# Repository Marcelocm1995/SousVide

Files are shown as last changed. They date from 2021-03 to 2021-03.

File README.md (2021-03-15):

# SousVide
This project is a thermo-circulator for cooking meats, fishes, etc. It's consists, basically, in a resistance thats heat up water at pre-determinatade temperature and time(or not).

# Bill Of Materials
* 500 Watts resistance
* DS18B20 Temperature sensor
* Water pump (from aquarium)
* 5V power supply (from smartphone charger)
* BluePill (STM32F103C8T6) 
* Rotary Encoder
* OLED DISPLAY
* 5V Relay
* 1N4148 Diode
* 5V Beep
* 2x BC548 transistors
* 3x 4k7 resistors
* 5mm LED
* 1k resistor

# How It Works:
This project have two operations modes:
* Heat(Aquecimento), will only heat water and keep at user determinatade temperature for indeterminatade time.
* Cooking (Cozinhar), will heat and keep water temperature for user determinatade temperature and time.

# Software:
It uses cubeMX for generate a pre-code. Compiler Keil uVision, but you can easily migrate to another suported compiler by cubeMX, like IAR.
The software first shows on display the operations modes for user and wait for a choice. Case Heat (aquecimento) mode is chose, display will ask for witch temperature user want to set, and will start the heating process. In this mode, when temperature achieve the setpoint some beeps will be emitted.
Case Cooking (Cozinhar) mode is chose, display will ask for witch temperature user want to set, and then witch time user want to set. In this mode, when timer done some beeps will be emitted.
To cancel any of these process is necessary to hold on encoder button for some seconds.

**You need to extract the "Drivers.zip" to compile this software**

## Control
It uses a simple bang-bang control (on/off) with a offset of +/- 0.2°C, but if you want it have a PID mode (at line 48 of main.c, uncalibrated).

## Debug
It have a USB CDC for debug, to enable this uncomment line 58 of main.c

# Hardware:
This hardware uses the schematic bellow:

<a href="https://imgur.com/b3Bf7M9">source: imgur.com</a>

* The signal pin is a PWM working with 0% or 100% in bang-bang mode, in PID mode you will need a solid-state relay.
* Use a power supply at least 250mA.
* Pay attention with current capacite of conductors in heater part 
* Use a shielded waterproof DS18B20

# Enclosure
I made a 3D printed enclosure for this project, STL's and STEP's are avaiable for download on this repository.
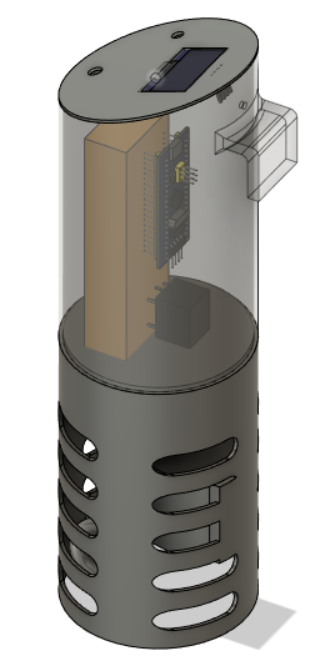
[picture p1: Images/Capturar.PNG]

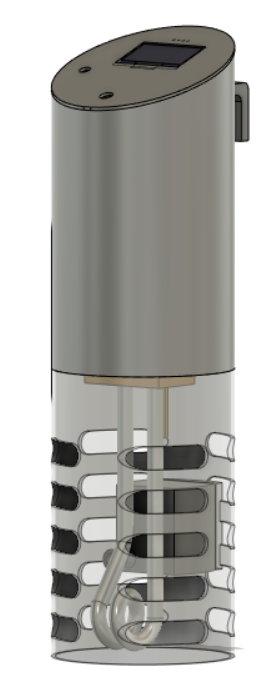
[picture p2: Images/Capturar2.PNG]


# Assembly
The middle part of enclosure needs to seal with silicone, like bellow:
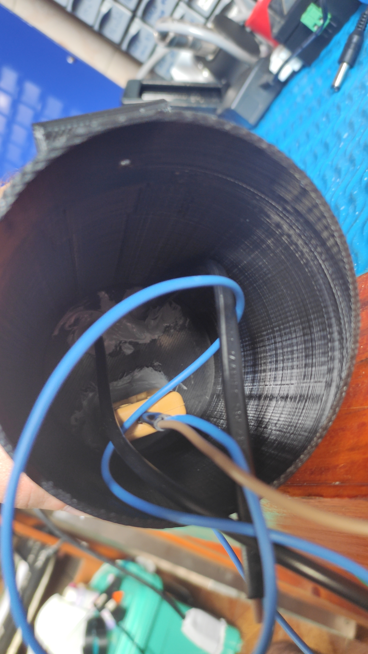
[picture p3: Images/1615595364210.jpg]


# Final project
alt text for screen readers Text to show on mouseover
IMAGE ALT TEXT HERE (https://www.youtube.com/watch?v=m6A6xz97m30)

https://www.youtube.com/watch?v=m6A6xz97m30

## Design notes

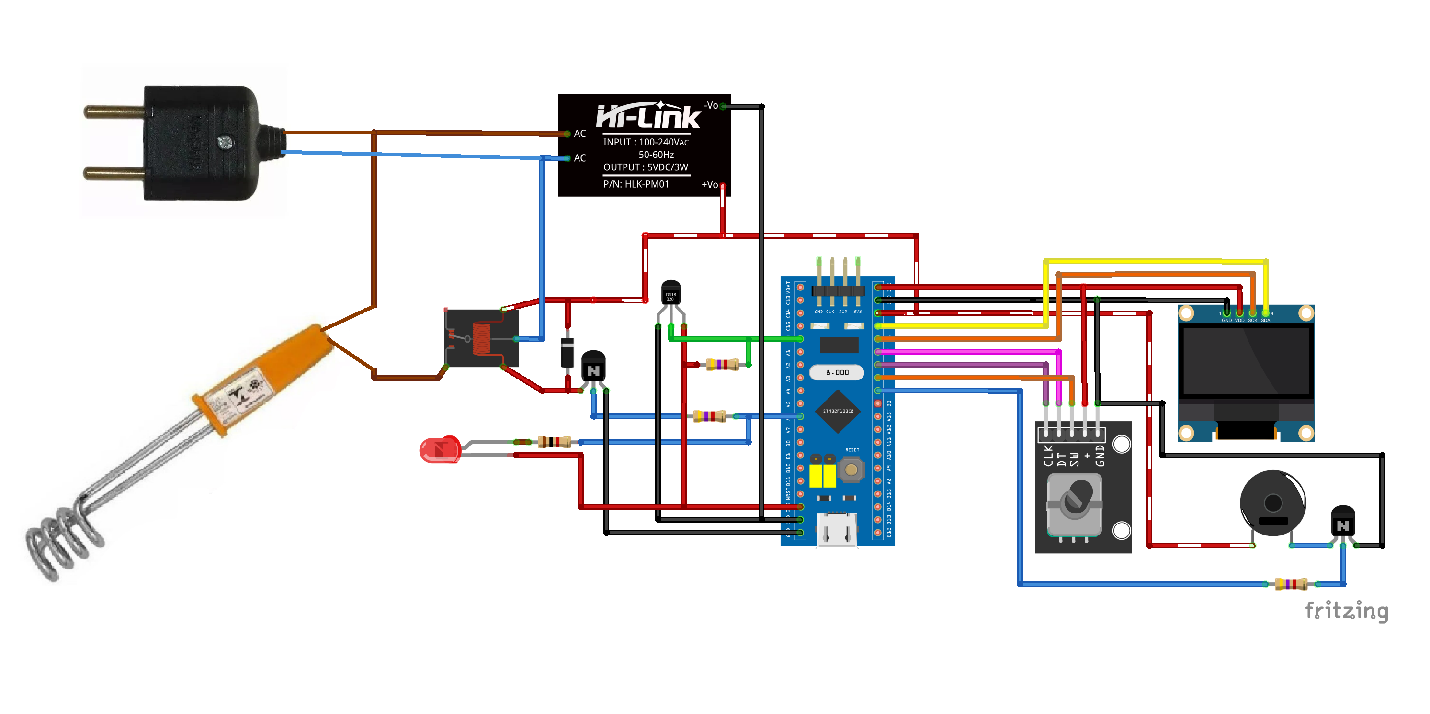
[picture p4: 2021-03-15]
Images/Untitled Sketch_bb.png

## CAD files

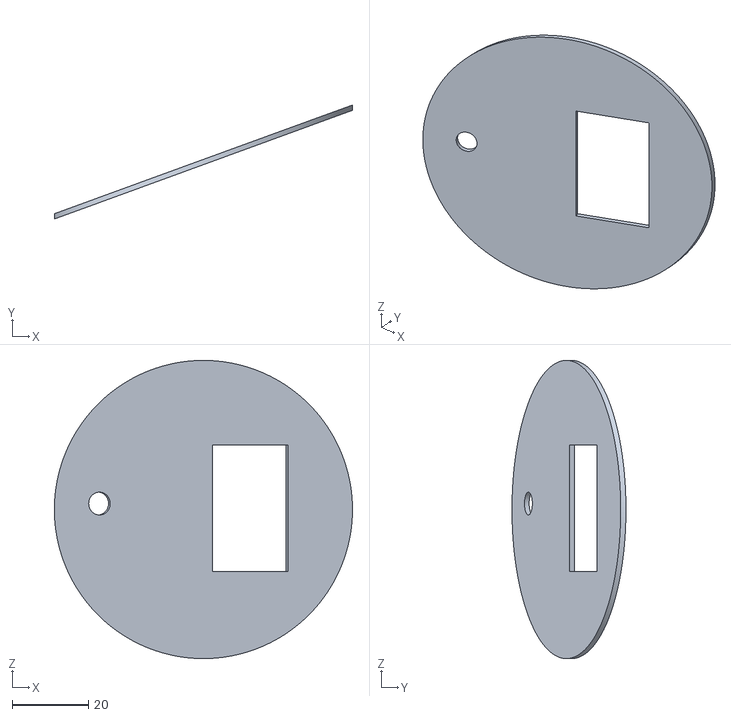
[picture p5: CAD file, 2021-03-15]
STL/tampa_superior.stl
78.2 x 29.9 x 78.2

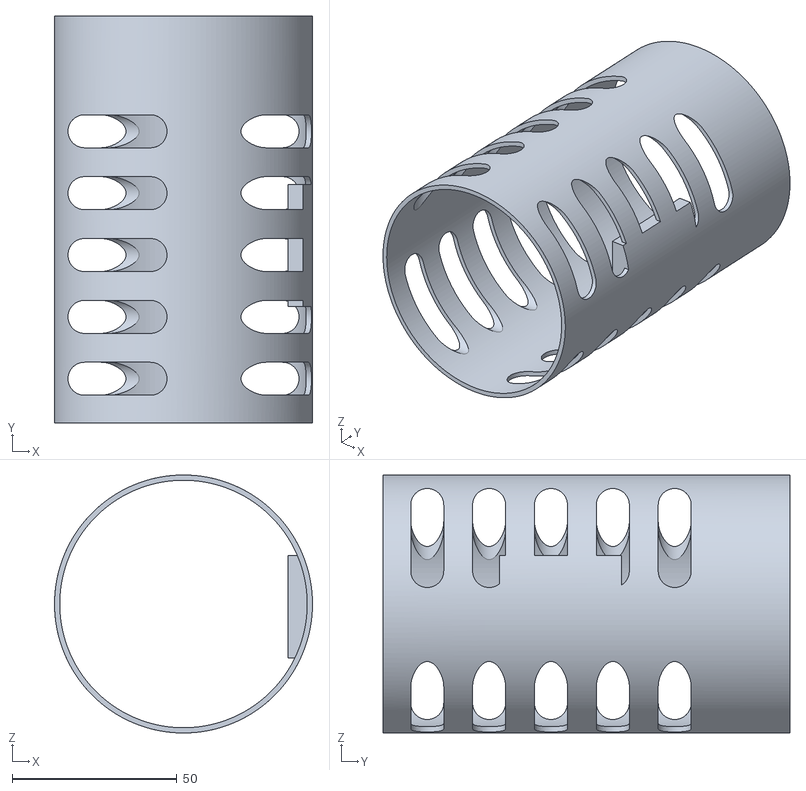
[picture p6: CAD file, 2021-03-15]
STL/corpo_inferior.stl
78.2 x 123.4 x 78.2

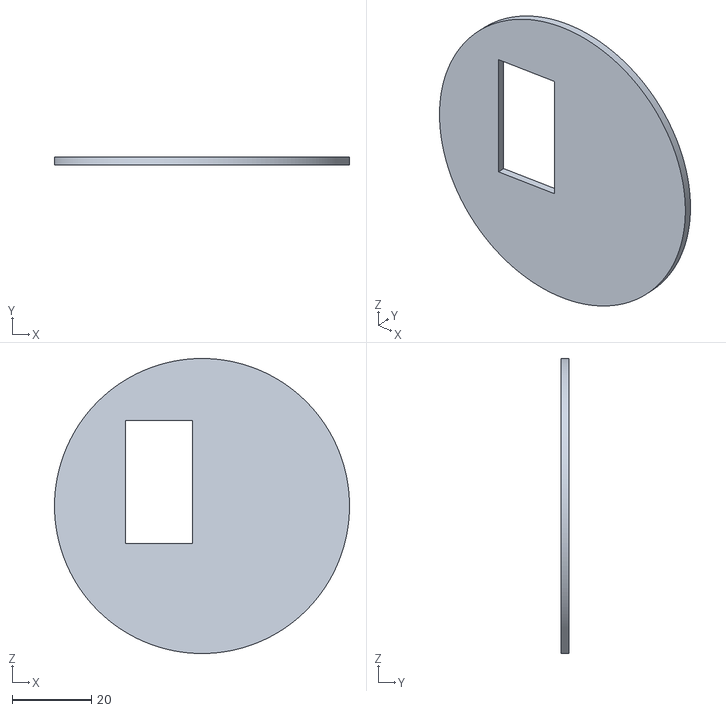
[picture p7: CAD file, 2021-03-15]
STL/tampa_inferior.stl
74.6 x 2.00 x 74.6

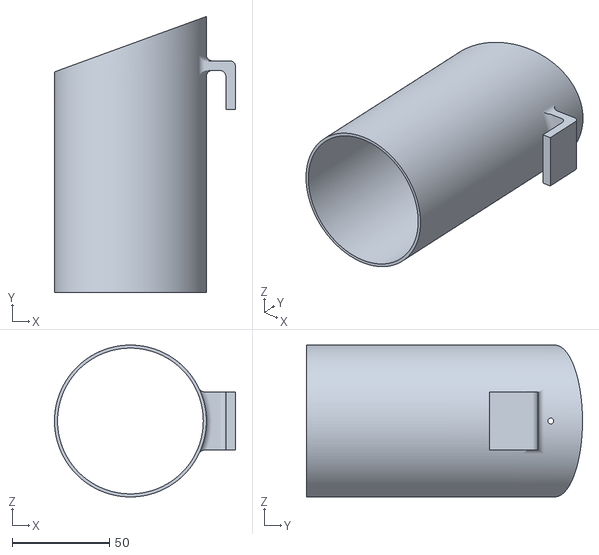
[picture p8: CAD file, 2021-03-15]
STL/corpo_superior.stl
93.2 x 142.1 x 78.2

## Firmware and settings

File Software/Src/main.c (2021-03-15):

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
/* Includes ------------------------------------------------------------------*/
#include "main.h"
#include "usb_device.h"

/* USER CODE BEGIN Includes */

#include "fonts.h"
#include "ssd1306.h"
#include "test.h"
#include "string.h"
#include "stdio.h"
#include "stdlib.h"
#include "usbd_cdc_if.h"

/* USER CODE END Includes */

/* USER CODE BEGIN PD */

//#define USE_PID
//#define USE_FILTER

#ifdef USE_PID
#define Kp 1.0
#define Ki 1.0
#define Kd 1.0
#define SAMPLE_TIME 1
#endif

#define DS18B20_PORT GPIOA
#define DS18B20_PIN GPIO_PIN_1

//#define DEBUG

/* USER CODE END PD */

/* USER CODE BEGIN PM */

#define LED_ON HAL_GPIO_WritePin(LED1_GPIO_Port, LED1_Pin, GPIO_PIN_RESET)
#define LED_OFF HAL_GPIO_WritePin(LED1_GPIO_Port, LED1_Pin, GPIO_PIN_SET)

#define BEEP_ON HAL_GPIO_WritePin(BUZZER_GPIO_Port, BUZZER_Pin, GPIO_PIN_SET)
#define BEEP_OFF HAL_GPIO_WritePin(BUZZER_GPIO_Port, BUZZER_Pin, GPIO_PIN_RESET)

/* USER CODE END PM */

ADC_HandleTypeDef hadc1;

I2C_HandleTypeDef hi2c1;

TIM_HandleTypeDef htim1;
TIM_HandleTypeDef htim2;
TIM_HandleTypeDef htim3;
TIM_HandleTypeDef htim4;

/* USER CODE BEGIN PV */
int TEMPOOO;
int SECOND_TIMER;

int SECOND, MINUTE, HOUR;
int SET_SECOND, SET_MINUTE, SET_HOUR;
int TOTAL_SET_SECOND;
int TOTAL_SET_SECOND_COUNTDOWN;

unsigned int SETPOINT_TEMPERAURE;

float TEMPERATURE, 
			LAST_TEMPERATURE,
			TEMPERATURE_RAW,
			FILTER_FACTOR = 5,
			Ts = 1.0f,
			TEMPERATURE_OFFSET = 0.2f;

float ERROR_MEASURED;
float PROPORTIONAL;
float INTEGRATOR;
float DERIVATIVE;
float PID;

int BLYNK_OLED;

int encoderCount, encoderDirection;
int SW_ALREADY_PRESSED;


char strbuffer[64];

int liga = 0;


/* USER CODE END PV */

void SystemClock_Config(void);
static void MX_GPIO_Init(void);
static void MX_ADC1_Init(void);
static void MX_TIM4_Init(void);
static void MX_I2C1_Init(void);
static void MX_TIM3_Init(void);
static void MX_TIM1_Init(void);
static void MX_TIM2_Init(void);
/* USER CODE BEGIN PFP */

float Temp_Read(void);
void heat_function(void);
void cook_function(void);
void delay_us (uint16_t us);
void Set_Pin_Output (GPIO_TypeDef *GPIOx, uint16_t GPIO_Pin);
void Set_Pin_Input (GPIO_TypeDef *GPIOx, uint16_t GPIO_Pin);
uint8_t DS18B20_Start (void);
void DS18B20_Write (uint8_t data);
uint8_t DS18B20_Read (void);
void beep(int delay);

extern uint8_t CDC_Transmit_FS(uint8_t* Buf, uint16_t Len);

/* USER CODE END PFP */

/**
  * @brief  The application entry point.
  * @retval int
  */
int main(void)
{
  /* MCU Configuration--------------------------------------------------------*/

  /* Reset of all peripherals, Initializes the Flash interface and the Systick. */
  HAL_Init();

  /* Configure the system clock */
  SystemClock_Config();

  /* Initialize all configured peripherals */
  MX_GPIO_Init();
  MX_ADC1_Init();
  MX_TIM4_Init();
  MX_USB_DEVICE_Init();
  MX_I2C1_Init();
  MX_TIM3_Init();
  MX_TIM1_Init();
  MX_TIM2_Init();
  /* USER CODE BEGIN 2 */

	HAL_Delay(1000);
		
	char strBuffer[] = "Ola\n\r";
	CDC_Transmit_FS((uint8_t*)strBuffer, strlen(strBuffer));
	
	SSD1306_Init();  // initialise
	SSD1306_Clear();
	
	beep(200);
	   
	SSD1306_GotoXY (2,0);
  SSD1306_Puts("Sous", &Font_16x26, 1);
  SSD1306_GotoXY (60, 30);
  SSD1306_Puts("Vide", &Font_16x26, 1);
  SSD1306_UpdateScreen(); //display

	HAL_TIM_Encoder_Start(&htim4, TIM_CHANNEL_ALL);
	__HAL_TIM_SET_AUTORELOAD(&htim4, 4*2);
	
	HAL_TIM_PWM_Start(&htim3, TIM_CHANNEL_1);
	__HAL_TIM_SET_COMPARE(&htim3, TIM_CHANNEL_1, 0);
	
	LED_ON;
	HAL_Delay(2000);
	SSD1306_Clear();
	
	HAL_TIM_Base_Start(&htim2);
	
	LED_OFF;
			
  /* USER CODE END 2 */

  /* Infinite loop */
  /* USER CODE BEGIN WHILE */
  while (1)
  {
		encoderCount = __HAL_TIM_GET_COUNTER(&htim4) / 4;
		SSD1306_GotoXY (22,0);
		SSD1306_Puts("Aquecer", &Font_11x18, 1);
		SSD1306_GotoXY (22,30);
		SSD1306_Puts("Cozinhar", &Font_11x18, 1);
		
		char strBuffer[] = "Ola\n\r";
		CDC_Transmit_FS((uint8_t*)strBuffer, strlen(strBuffer));
		
		if(encoderCount == 1)
		{
			SSD1306_GotoXY (0,0);
			SSD1306_Puts("->", &Font_11x18, 1);
			SSD1306_GotoXY (0,30);
			SSD1306_Puts("  ", &Font_11x18, 1);
		}
		
		if(encoderCount == 0)
		{
			SSD1306_GotoXY (0,30);
			SSD1306_Puts("->", &Font_11x18, 1);
			SSD1306_GotoXY (0,0);
			SSD1306_Puts("  ", &Font_11x18, 1);
		}
		SSD1306_UpdateScreen();
		
		if((HAL_GPIO_ReadPin(SW_ENC_GPIO_Port, SW_ENC_Pin) == 1) && (SW_ALREADY_PRESSED == 1))
				SW_ALREADY_PRESSED = 0;
		
		if((HAL_GPIO_ReadPin(SW_ENC_GPIO_Port, SW_ENC_Pin) == 0) && (SW_ALREADY_PRESSED == 0))
			{
				HAL_Delay(100);
				if((HAL_GPIO_ReadPin(SW_ENC_GPIO_Port, SW_ENC_Pin) == 0) && (SW_ALREADY_PRESSED == 0))
				{
					SW_ALREADY_PRESSED = 1;
					beep(200);
					if(encoderCount == 1)
					{
						SSD1306_Clear();
						heat_function();
						__HAL_TIM_SET_COUNTER(&htim4, 0);
					}
					else
					{
						SSD1306_Clear();
						cook_function();
						__HAL_TIM_SET_COUNTER(&htim4, 0);
					}
				}
			}
		
    /* USER CODE END WHILE */

    /* USER CODE BEGIN 3 */
  }
  /* USER CODE END 3 */
}

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
/* USER CODE BEGIN 4 */

void heat_function(void)
{
	int STAGE = 0;
	
	sprintf(strbuffer, "Selecione a");
	SSD1306_GotoXY(2, 0);
	SSD1306_Puts(strbuffer, &Font_11x18, 1);
	
	sprintf(strbuffer, "Temperatura");
	SSD1306_GotoXY(2, 20);
	SSD1306_Puts(strbuffer, &Font_11x18, 1);
	
	__HAL_TIM_SET_COUNTER(&htim4, 0);
	__HAL_TIM_SET_AUTORELOAD(&htim4, (4 * 100)-1);
  while(STAGE == 0)
	{
		encoderCount = __HAL_TIM_GET_COUNTER(&htim4)/4;	
		sprintf(strbuffer, "%02i C",encoderCount);
		SSD1306_GotoXY(40, 42);
		SSD1306_Puts(strbuffer, &Font_11x18, 0);
		SSD1306_UpdateScreen();
		
		if((HAL_GPIO_ReadPin(SW_ENC_GPIO_Port, SW_ENC_Pin) == 1) && (SW_ALREADY_PRESSED == 1))
			SW_ALREADY_PRESSED = 0;
		
		if((HAL_GPIO_ReadPin(SW_ENC_GPIO_Port, SW_ENC_Pin) == 0) && (SW_ALREADY_PRESSED == 0))
		{
			HAL_Delay(100);
			if((HAL_GPIO_ReadPin(SW_ENC_GPIO_Port, SW_ENC_Pin) == 0) && (SW_ALREADY_PRESSED == 0))
			{
				SW_ALREADY_PRESSED = 1;
				beep(200);
				STAGE++;
				SETPOINT_TEMPERAURE = encoderCount;
				SSD1306_Clear();
			}
		}
	}
	
	while(STAGE == 1)
	{
		int t_in = HAL_GetTick();
		
		#ifdef USE_FILTER
		TEMPERATURE_RAW = Temp_Read();
		TEMPERATURE =  ((FILTER_FACTOR * Ts * TEMPERATURE_RAW) + (LAST_TEMPERATURE)) /( 1 + (FILTER_FACTOR * Ts));
    LAST_TEMPERATURE = TEMPERATURE;
		
		#else
		TEMPERATURE = Temp_Read();
		
		#endif
		
		#ifdef USE_PID
    ERROR_MEASURED = SETPOINT_TEMPERAURE - TEMPERATURE;
    
    PROPORTIONAL = Kp * ERROR_MEASURED;
    INTEGRATOR += (Ki * ERROR_MEASURED) * SAMPLE_TIME;
    DERIVATIVE = ((TEMPERATURE - LAST_TEMPERATURE) * Kd) / SAMPLE_TIME;
   
		if(INTEGRATOR > 1000)
			INTEGRATOR = 1000;
	 
		if(INTEGRATOR < 0)
			INTEGRATOR = 0;
    

    PID = PROPORTIONAL + INTEGRATOR - DERIVATIVE;
    
		__HAL_TIM_SET_COMPARE(&htim3, TIM_CHANNEL_1, PID);
    
		LAST_TEMPERATURE = TEMPERATURE;
		
		#else
		if(TEMPERATURE > SETPOINT_TEMPERAURE + TEMPERATURE_OFFSET)
		{
			liga = 0;
			beep(200);
			LED_OFF;
			__HAL_TIM_SET_COMPARE(&htim3, TIM_CHANNEL_1, 0);
		}
		
		if(TEMPERATURE < SETPOINT_TEMPERAURE - TEMPERATURE_OFFSET)
		{
			liga = 1;
			LED_ON;
			__HAL_TIM_SET_COMPARE(&htim3, TIM_CHANNEL_1, 100);
		}
		#endif
		
		HAL_Delay(156);//necessario para dar 1hz no ciclo
		
		BLYNK_OLED = !BLYNK_OLED;
		SSD1306_GotoXY(12, 0);
		SSD1306_Puts("Aquecendo", &Font_11x18, BLYNK_OLED);
		
		SSD1306_GotoXY(10, 35);
		SSD1306_Puts("Atual", &Font_7x10, 1);
		sprintf(strbuffer, "%.1fC ", TEMPERATURE);
		SSD1306_GotoXY(2, 45);
		SSD1306_Puts(strbuffer, &Font_11x18, 1);
		
		SSD1306_GotoXY(80, 35);
		SSD1306_Puts("Alvo", &Font_7x10, 1);
		sprintf(strbuffer, "%02iC", SETPOINT_TEMPERAURE);
		SSD1306_GotoXY(80, 45);
		SSD1306_Puts(strbuffer, &Font_11x18, 1);
		
		SSD1306_UpdateScreen();
		
		#ifdef DEBUG
		sprintf(strbuffer, "Temperatura atual %.1fC\n\r", TEMPERATURE);
		CDC_Transmit_FS((uint8_t*)strbuffer, strlen(strbuffer));
		sprintf(strbuffer, "Temperatura Alvo %iC\n\r", SETPOINT_TEMPERAURE);
		CDC_Transmit_FS((uint8_t*)strbuffer, strlen(strbuffer));
		#endif
		
		if((HAL_GPIO_ReadPin(SW_ENC_GPIO_Port, SW_ENC_Pin) == 1) && (SW_ALREADY_PRESSED == 1))
			SW_ALREADY_PRESSED = 0;
		
		if((HAL_GPIO_ReadPin(SW_ENC_GPIO_Port, SW_ENC_Pin) == 0) && (SW_ALREADY_PRESSED == 0))
		{
			HAL_Delay(1000);
			if((HAL_GPIO_ReadPin(SW_ENC_GPIO_Port, SW_ENC_Pin) == 0) && (SW_ALREADY_PRESSED == 0))
			{
				SW_ALREADY_PRESSED = 1;
				beep(200);
				__HAL_TIM_SET_COMPARE(&htim3, TIM_CHANNEL_1, 0);
				liga = 0;
				LED_OFF;
				SSD1306_Clear();
				return;
			}
		}
		int t_end = HAL_GetTick();
		TEMPOOO = t_end - t_in;
	}
}

void cook_function()
{
	int STAGE = 0;
	
	sprintf(strbuffer, "Selecione a");
	SSD1306_GotoXY(2, 0);
	SSD1306_Puts(strbuffer, &Font_11x18, 1);
	
	sprintf(strbuffer, "Temperatura");
	SSD1306_GotoXY(2, 20);
	SSD1306_Puts(strbuffer, &Font_11x18, 1);
	
	__HAL_TIM_SET_COUNTER(&htim4, 0);
	__HAL_TIM_SET_AUTORELOAD(&htim4, (4 * 100)-1);
  while(STAGE == 0)
	{
		encoderCount = __HAL_TIM_GET_COUNTER(&htim4)/4;
		sprintf(strbuffer, "%02i C",encoderCount);
		SSD1306_GotoXY(40, 42);
		SSD1306_Puts(strbuffer, &Font_11x18, 0);
		SSD1306_UpdateScreen();
		
		if((HAL_GPIO_ReadPin(SW_ENC_GPIO_Port, SW_ENC_Pin) == 1) && (SW_ALREADY_PRESSED == 1))
			SW_ALREADY_PRESSED = 0;
		
		if((HAL_GPIO_ReadPin(SW_ENC_GPIO_Port, SW_ENC_Pin) == 0) && (SW_ALREADY_PRESSED == 0))
		{
			HAL_Delay(100);
			if((HAL_GPIO_ReadPin(SW_ENC_GPIO_Port, SW_ENC_Pin) == 0) && (SW_ALREADY_PRESSED == 0))
			{
				SW_ALREADY_PRESSED = 1;
				beep(200);
				STAGE++;
				SETPOINT_TEMPERAURE = encoderCount;
			}
		}
	}
	SSD1306_Clear();
	sprintf(strbuffer, "Selecione o");
	SSD1306_GotoXY(2, 0);
	SSD1306_Puts(strbuffer, &Font_11x18, 1);
	
	sprintf(strbuffer, "Tempo       ");
	SSD1306_GotoXY(2, 20);
	SSD1306_Puts(strbuffer, &Font_11x18, 1);
	
	__HAL_TIM_SET_COUNTER(&htim4, 0);
	__HAL_TIM_SET_AUTORELOAD(&htim4, (4 * 100)-1);
  while(STAGE == 1)
	{
		encoderCount = __HAL_TIM_GET_COUNTER(&htim4)/4;
		sprintf(strbuffer, "%02ih",encoderCount);
		SSD1306_GotoXY(2, 40);
		SSD1306_Puts(strbuffer, &Font_11x18, 0);
		
		sprintf(strbuffer, ":00m:00s");
		SSD1306_Puts(strbuffer, &Font_11x18, 1);
		
		SSD1306_UpdateScreen();
		
		if((HAL_GPIO_ReadPin(SW_ENC_GPIO_Port, SW_ENC_Pin) == 1) && (SW_ALREADY_PRESSED == 1))
			SW_ALREADY_PRESSED = 0;
		
		if((HAL_GPIO_ReadPin(SW_ENC_GPIO_Port, SW_ENC_Pin) == 0) && (SW_ALREADY_PRESSED == 0))
		{
			HAL_Delay(100);
			if((HAL_GPIO_ReadPin(SW_ENC_GPIO_Port, SW_ENC_Pin) == 0) && (SW_ALREADY_PRESSED == 0))
			{
				SW_ALREADY_PRESSED = 1;
				beep(200);
				STAGE++;
				SET_HOUR = encoderCount;
			}
		}
	}
	
	__HAL_TIM_SET_COUNTER(&htim4, 0);
	__HAL_TIM_SET_AUTORELOAD(&htim4, 4 * 60);
  while(STAGE == 2)
	{
		encoderCount = __HAL_TIM_GET_COUNTER(&htim4)/4;
		sprintf(strbuffer, "%02ih:", SET_HOUR);
		SSD1306_GotoXY(2, 40);
		SSD1306_Puts(strbuffer, &Font_11x18, 1);
		
		sprintf(strbuffer, "%02im", encoderCount);
		SSD1306_Puts(strbuffer, &Font_11x18, 0);
		
		sprintf(strbuffer, ":00s");
		SSD1306_Puts(strbuffer, &Font_11x18, 1);
		
		SSD1306_UpdateScreen();
		
		if((HAL_GPIO_ReadPin(SW_ENC_GPIO_Port, SW_ENC_Pin) == 1) && (SW_ALREADY_PRESSED == 1))
			SW_ALREADY_PRESSED = 0;
		
		if((HAL_GPIO_ReadPin(SW_ENC_GPIO_Port, SW_ENC_Pin) == 0) && (SW_ALREADY_PRESSED == 0))
		{
			HAL_Delay(100);
			if((HAL_GPIO_ReadPin(SW_ENC_GPIO_Port, SW_ENC_Pin) == 0) && (SW_ALREADY_PRESSED == 0))
			{
				SW_ALREADY_PRESSED = 1;
				beep(200);
				STAGE++;
				SET_MINUTE = encoderCount;
			}
		}
	}
	
	__HAL_TIM_SET_COUNTER(&htim4, 0);
	__HAL_TIM_SET_AUTORELOAD(&htim4, 4 * 60);
  while(STAGE == 3)
	{
		encoderCount = __HAL_TIM_GET_COUNTER(&htim4)/4;
		sprintf(strbuffer, "%02ih:", SET_HOUR);
		SSD1306_GotoXY(2, 40);
		SSD1306_Puts(strbuffer, &Font_11x18, 1);
		
		sprintf(strbuffer, "%02im:", SET_MINUTE);
		SSD1306_Puts(strbuffer, &Font_11x18, 1);
		
		sprintf(strbuffer, "%02is",encoderCount);
		SSD1306_Puts(strbuffer, &Font_11x18, 0);
		SSD1306_UpdateScreen();
		
		if((HAL_GPIO_ReadPin(SW_ENC_GPIO_Port, SW_ENC_Pin) == 1) && (SW_ALREADY_PRESSED == 1))
			SW_ALREADY_PRESSED = 0;
		
		if((HAL_GPIO_ReadPin(SW_ENC_GPIO_Port, SW_ENC_Pin) == 0) && (SW_ALREADY_PRESSED == 0))
		{
			HAL_Delay(100);
			if((HAL_GPIO_ReadPin(SW_ENC_GPIO_Port, SW_ENC_Pin) == 0) && (SW_ALREADY_PRESSED == 0))
			{
				SW_ALREADY_PRESSED = 1;
				beep(200);
				STAGE++;
				SET_SECOND = encoderCount;
			}
		}
	}
	
	SSD1306_Clear();
	HOUR = SET_HOUR; MINUTE = SET_MINUTE; SECOND = SET_SECOND;
	TOTAL_SET_SECOND = (SET_HOUR * 3600) + (SET_MINUTE * 60) + SET_SECOND;
	TOTAL_SET_SECOND_COUNTDOWN = TOTAL_SET_SECOND;
	SECOND_TIMER = 0;
	HAL_TIM_Base_Start_IT(&htim1);
	
	while((STAGE == 4) && (TOTAL_SET_SECOND > SECOND_TIMER))
	{
		int t_in = HAL_GetTick();
	
		#ifdef USE_FILTER
		TEMPERATURE_RAW = Temp_Read();
		TEMPERATURE =  ((FILTER_FACTOR * Ts * TEMPERATURE_RAW) + (LAST_TEMPERATURE)) /( 1 + (FILTER_FACTOR * Ts));
    LAST_TEMPERATURE = TEMPERATURE;
		
		#else
		TEMPERATURE = Temp_Read();
		
		#endif
		
		#ifdef USE_PID
    ERROR_MEASURED = SETPOINT_TEMPERAURE - TEMPERATURE;
    
    PROPORTIONAL = Kp * ERROR_MEASURED;
    INTEGRATOR += (Ki * ERROR_MEASURED) * SAMPLE_TIME;
    DERIVATIVE = ((TEMPERATURE - LAST_TEMPERATURE) * Kd) / SAMPLE_TIME;
   
		if(INTEGRATOR > 1000)
			INTEGRATOR = 1000;
	 
		if(INTEGRATOR < 0)
			INTEGRATOR = 0;
    

    PID = PROPORTIONAL + INTEGRATOR - DERIVATIVE;
    
		__HAL_TIM_SET_COMPARE(&htim3, TIM_CHANNEL_1, PID);
    
		LAST_TEMPERATURE = TEMPERATURE;
		#else
		if(TEMPERATURE > SETPOINT_TEMPERAURE + TEMPERATURE_OFFSET)
		{
			liga = 0;
			LED_OFF;
			__HAL_TIM_SET_COMPARE(&htim3, TIM_CHANNEL_1, 0);
		}
		
		if(TEMPERATURE < SETPOINT_TEMPERAURE - TEMPERATURE_OFFSET)
		{
			liga = 1;
			LED_ON;
			__HAL_TIM_SET_COMPARE(&htim3, TIM_CHANNEL_1, 100);
		}
		#endif
		
		HAL_Delay(153);//necessario para dar 1hz no ciclo
		
		HOUR = TOTAL_SET_SECOND_COUNTDOWN / 3600;
		MINUTE = (TOTAL_SET_SECOND_COUNTDOWN % 3600) / 60;
		SECOND = (TOTAL_SET_SECOND_COUNTDOWN % 3600) % 60;
		
		BLYNK_OLED = !BLYNK_OLED;
		SSD1306_GotoXY(10, 0);
		SSD1306_Puts("Tempo faltante", &Font_7x10, BLYNK_OLED);
		sprintf(strbuffer, "%02ih:%02im:%02is", HOUR, MINUTE, SECOND);
		SSD1306_GotoXY(4, 11);
		SSD1306_Puts(strbuffer, &Font_11x18, 1);
		
		SSD1306_GotoXY(10, 35);
		SSD1306_Puts("Atual", &Font_7x10, 1);
		sprintf(strbuffer, "%.1fC ", TEMPERATURE);
		SSD1306_GotoXY(2, 45);
		SSD1306_Puts(strbuffer, &Font_11x18, 1);
		
		SSD1306_GotoXY(80, 35);
		SSD1306_Puts("Alvo", &Font_7x10, 1);
		sprintf(strbuffer, "%02iC", SETPOINT_TEMPERAURE);
		SSD1306_GotoXY(80, 45);
		SSD1306_Puts(strbuffer, &Font_11x18, 1);
		
		SSD1306_UpdateScreen();
		
		#ifdef DEBUG
		sprintf(strbuffer, "\nTempo faltante %02ih:%02im:%02is\n", HOUR, MINUTE, SECOND);
		CDC_Transmit_FS((uint8_t*)strbuffer, strlen(strbuffer));
		sprintf(strbuffer, "Temperatura atual %.1fC\n", TEMPERATURE);
		CDC_Transmit_FS((uint8_t*)strbuffer, strlen(strbuffer));
		sprintf(strbuffer, "Temperatura alvo %iC\n", SETPOINT_TEMPERAURE);
		CDC_Transmit_FS((uint8_t*)strbuffer, strlen(strbuffer));
		#endif
		
		if((HAL_GPIO_ReadPin(SW_ENC_GPIO_Port, SW_ENC_Pin) == 1) && (SW_ALREADY_PRESSED == 1))
			SW_ALREADY_PRESSED = 0;
		
		if((HAL_GPIO_ReadPin(SW_ENC_GPIO_Port, SW_ENC_Pin) == 0) && (SW_ALREADY_PRESSED == 0))
		{
			HAL_Delay(3000);
			if((HAL_GPIO_ReadPin(SW_ENC_GPIO_Port, SW_ENC_Pin) == 0) && (SW_ALREADY_PRESSED == 0))
			{
				SW_ALREADY_PRESSED = 1;
				beep(200);
				__HAL_TIM_SET_COMPARE(&htim3, TIM_CHANNEL_1, 0);
				SSD1306_Clear();
				HAL_TIM_Base_Stop_IT(&htim1);
				__HAL_TIM_SET_COUNTER(&htim1, 0);
				liga = 0;
				LED_OFF;
				for(int k = 0; k < 3; k++)
				{
					BEEP_ON;
					LED_ON;
					HAL_Delay(200);
					BEEP_OFF;
					LED_OFF;
					HAL_Delay(100);
				}
				return;
			}
		}
		int t_end = HAL_GetTick();
		TEMPOOO = t_end - t_in;
	}	
	HAL_TIM_Base_Stop_IT(&htim1);
	liga = 0;
	__HAL_TIM_SET_COMPARE(&htim3, TIM_CHANNEL_1, 0);
	HAL_Delay(1000);
	SSD1306_Clear();
	STAGE = 5;
	
	for(int k = 0; k < 3; k++)
	{
		BEEP_ON;
		LED_ON;
		HAL_Delay(200);
		
		BEEP_OFF;
		LED_OFF;
		HAL_Delay(100);
	}
	
	while(STAGE == 5)
	{		
		SSD1306_GotoXY(2, 0);
		SSD1306_Puts("Cozimento", &Font_11x18, 1);
		SSD1306_GotoXY(2, 35);
		SSD1306_Puts("Finalizado", &Font_11x18, 1);
		SSD1306_UpdateScreen();
		
		if((HAL_GPIO_ReadPin(SW_ENC_GPIO_Port, SW_ENC_Pin) == 1) && (SW_ALREADY_PRESSED == 1))
			SW_ALREADY_PRESSED = 0;
		
		if((HAL_GPIO_ReadPin(SW_ENC_GPIO_Port, SW_ENC_Pin) == 0) && (SW_ALREADY_PRESSED == 0))
		{
			HAL_Delay(100);
			if((HAL_GPIO_ReadPin(SW_ENC_GPIO_Port, SW_ENC_Pin) == 0) && (SW_ALREADY_PRESSED == 0))
			{
				SW_ALREADY_PRESSED = 1;
				beep(200);
				SSD1306_Clear();
				return;
			}
		}
	}
}

void beep(int delay)
{
	HAL_GPIO_WritePin(BUZZER_GPIO_Port, BUZZER_Pin, GPIO_PIN_SET);
	HAL_Delay(delay/2);
	HAL_GPIO_WritePin(BUZZER_GPIO_Port, BUZZER_Pin, GPIO_PIN_RESET);
	HAL_Delay(delay/2);
}
void HAL_TIM_PeriodElapsedCallback(TIM_HandleTypeDef *htim1)
{
	SECOND_TIMER++;
	TOTAL_SET_SECOND_COUNTDOWN--;
}

float Temp_Read(void)
{	
	float Temperature = 0;
	int16_t Presence = 0;
	int16_t Temp_byte1, Temp_byte2;
	int16_t TEMP;
	
	Presence = DS18B20_Start();
	HAL_Delay(1);
	DS18B20_Write (0xCC);  // skip ROM
	DS18B20_Write (0x44);  // convert t
	HAL_Delay(800); 

	Presence = DS18B20_Start();
  HAL_Delay(1);
  DS18B20_Write (0xCC);  // skip ROM
  DS18B20_Write (0xBE);  // Read Scratch-pad

  Temp_byte1 = DS18B20_Read();
	Temp_byte2 = DS18B20_Read();
	TEMP = (Temp_byte2<<8)|Temp_byte1;
	Temperature = (float)TEMP/16.0;

	return Temperature;
	/*
	float adcVal;
	HAL_ADC_Start(&hadc1);
	HAL_ADC_PollForConversion(&hadc1, 1);
	adcVal = HAL_ADC_GetValue(&hadc1);
	HAL_ADC_Stop(&hadc1);
	return adcVal;
	*/
}

void delay_us (uint16_t us)
{
	__HAL_TIM_SET_COUNTER(&htim2,0);  // set the counter value a 0
	while (__HAL_TIM_GET_COUNTER(&htim2) < us);  // wait for the counter to reach the us input in the parameter
}

void Set_Pin_Output (GPIO_TypeDef *GPIOx, uint16_t GPIO_Pin)
{
	GPIO_InitTypeDef GPIO_InitStruct = {0};
	GPIO_InitStruct.Pin = GPIO_Pin;
	GPIO_InitStruct.Mode = GPIO_MODE_OUTPUT_PP;
	GPIO_InitStruct.Speed = GPIO_SPEED_FREQ_LOW;
	HAL_GPIO_Init(GPIOx, &GPIO_InitStruct);
}

void Set_Pin_Input (GPIO_TypeDef *GPIOx, uint16_t GPIO_Pin)
{
	GPIO_InitTypeDef GPIO_InitStruct = {0};
	GPIO_InitStruct.Pin = GPIO_Pin;
	GPIO_InitStruct.Mode = GPIO_MODE_INPUT;
	GPIO_InitStruct.Pull = GPIO_PULLUP;
	HAL_GPIO_Init(GPIOx, &GPIO_InitStruct);
}

uint8_t DS18B20_Start (void)
{
	uint8_t Response = 0;
	Set_Pin_Output(DS18B20_PORT, DS18B20_PIN);   // set the pin as output
	HAL_GPIO_WritePin (DS18B20_PORT, DS18B20_PIN, GPIO_PIN_RESET);  // pull the pin low
	delay_us(480);   // delay according to datasheet

	Set_Pin_Input(DS18B20_PORT, DS18B20_PIN);    // set the pin as input
	delay_us(80);    // delay according to datasheet

	if (!(HAL_GPIO_ReadPin (DS18B20_PORT, DS18B20_PIN))) Response = 1;    // if the pin is low i.e the presence pulse is detected
	else Response = -1;

	delay_us(400); // 480 us delay totally.

	return Response;
}

void DS18B20_Write (uint8_t data)
{
	Set_Pin_Output(DS18B20_PORT, DS18B20_PIN);  // set as output

	for (int i=0; i<8; i++)
	{

		if ((data & (1<<i))!=0)  // if the bit is high
		{
			// write 1

			Set_Pin_Output(DS18B20_PORT, DS18B20_PIN);  // set as output
			HAL_GPIO_WritePin (DS18B20_PORT, DS18B20_PIN, GPIO_PIN_RESET);  // pull the pin LOW
			delay_us(1);  // wait for 1 us

			Set_Pin_Input(DS18B20_PORT, DS18B20_PIN);  // set as input
			delay_us(50);  // wait for 60 us
		}

		else  // if the bit is low
		{
			// write 0

			Set_Pin_Output(DS18B20_PORT, DS18B20_PIN);
			HAL_GPIO_WritePin (DS18B20_PORT, DS18B20_PIN, GPIO_PIN_RESET);  // pull the pin LOW
			delay_us(50);  // wait for 60 us

			Set_Pin_Input(DS18B20_PORT, DS18B20_PIN);
		}
	}
}

uint8_t DS18B20_Read (void)
{
	uint8_t value=0;

	Set_Pin_Input(DS18B20_PORT, DS18B20_PIN);

	for (int i=0;i<8;i++)
	{
		Set_Pin_Output(DS18B20_PORT, DS18B20_PIN);   // set as output

		HAL_GPIO_WritePin (DS18B20_PORT, DS18B20_PIN, GPIO_PIN_RESET);  // pull the data pin LOW
		delay_us(1);  // wait for > 1us

		Set_Pin_Input(DS18B20_PORT, DS18B20_PIN);  // set as input
		if (HAL_GPIO_ReadPin (DS18B20_PORT, DS18B20_PIN))  // if the pin is HIGH
		{
			value |= 1<<i;  // read = 1
		}
		delay_us(50);  // wait for 60 us
	}
	return value;
}

/* USER CODE END 4 */
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


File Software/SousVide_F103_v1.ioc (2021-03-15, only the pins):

Mcu.UserName=STM32F103CBTx
PA0-WKUP.Signal=ADCx_IN0
PA11.Signal=USB_DM
PA12.Signal=USB_DP
PA13.Signal=SYS_JTMS-SWDIO
PA14.Signal=SYS_JTCK-SWCLK
PA6.Signal=S_TIM3_CH1
PB4.GPIO_Label=BUZZER
PB4.Signal=GPIO_Output
PB5.GPIO_Label=SW_ENC
PB5.Signal=GPIO_Input
PB6.Signal=S_TIM4_CH1
PB7.Signal=S_TIM4_CH2
PB8.Signal=I2C1_SCL
PB9.Signal=I2C1_SDA
PC13-TAMPER-RTC.GPIO_Label=LED1
PC13-TAMPER-RTC.Signal=GPIO_Output
PC14-OSC32_IN.Signal=RCC_OSC32_IN
PC15-OSC32_OUT.Signal=RCC_OSC32_OUT
PD0-OSC_IN.Signal=RCC_OSC_IN
PD1-OSC_OUT.Signal=RCC_OSC_OUT

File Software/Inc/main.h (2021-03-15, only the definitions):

#define LED1_Pin GPIO_PIN_13
#define LED1_GPIO_Port GPIOC
#define BUZZER_Pin GPIO_PIN_4
#define BUZZER_GPIO_Port GPIOB
#define SW_ENC_Pin GPIO_PIN_5
#define SW_ENC_GPIO_Port GPIOB

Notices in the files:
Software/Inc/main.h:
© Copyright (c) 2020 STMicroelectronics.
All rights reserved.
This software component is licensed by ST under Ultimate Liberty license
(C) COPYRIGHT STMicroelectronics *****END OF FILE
